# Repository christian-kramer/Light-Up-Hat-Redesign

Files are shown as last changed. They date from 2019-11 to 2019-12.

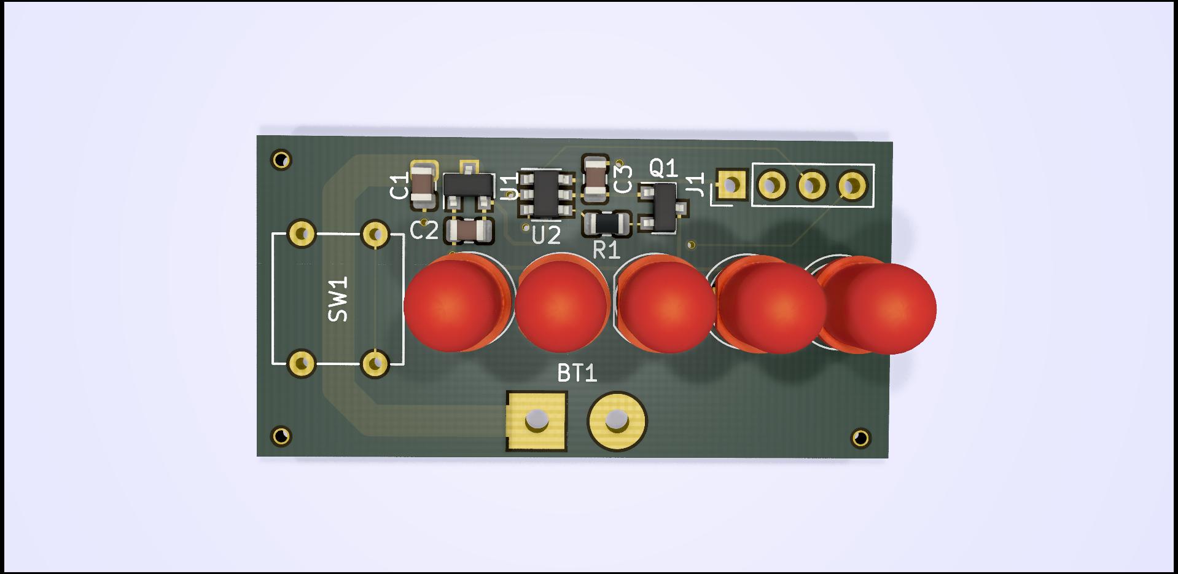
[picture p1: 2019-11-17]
Images/Render.jpg

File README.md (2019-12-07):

# Light-Up-Hat-Redesign
Putting wearable technology in a winter hat

---

Most people, when talking about "hats" in the hobbyist embedded world, are referring to little devices that fit on top of a Raspberry Pi. But no, I'm talking about an actual hat... like the one that goes on your head.

It all starts with a mistake; letting my winter hat with a built-in headlamp go through my wash without taking the electronics out first.

Now, these things aren't terribly expensive to replace. Mine was just $13 on Amazon.

LED Beanie

But being savvy with electronics, I decided I wanted to try to fix mine. But... what I found was rather disheartening.

LED Beanie Circuitry

These things are cheap for a reason, and that reason is they're not very well built. The wires of the battery pack were just barely soldered onto the LED contacts to begin with... any fix I did to this thing was still going to be temporary. Add to that the annoyance of having to turn the switch on the battery pack off with my fingernail, and... I smelled an opportunity for an improvement. To the drawing board!

I knew I wanted to keep the "5-LED array" form factor, but I also wanted a button next to the LEDs I could push to toggle them on and off, so I didn't have to take off my gloves like I currently had to do. I spent a lot of time trying to figure out an all-analog method of doing this push button that didn't require many components. But in the end, I decided I should use up those PIC10F220s I had ordered for my first-ever circuit boards I designed a year ago.

Here's what I came up with for a board:

Hat PCB Render

First off, we've got some nice big through-hole pads for the battery wires to connect to. I want to be able to yank on those things without even budging. Next, we've got the on/off push-button. I decided to use these silicone "soundless tact switches" in place of the typical clicky kind. That way I didn't have to use much force, allowing me to keep my gloves on.

Tact Switch

The battery leads into the nifty XC6206 SOT-23 3.3v regulator I found on eBay from Torex. At $0.40, they're a steal to save some space.

XC6206

The regulator then leads into the ever-faithful PIC10F220, which handles the input of the button and also controls a 2n3906 PNP transistor, also in a SOT-23 package. This drives the 5 LEDs, which should give us plenty of light!

Finally, everything arrived in the mail.

Board Face 1
Board Face 2

The boards turned out great! I opted for black so it would match the hat color, and because I absolutely love JLCPCB's matte black solder mask.

On to assembly!

Assembled

Once everything was put together... it didn't work! No matter what I did, the PIC10F220 just wouldn't talk to my PC! I was starting to have flashbacks to a year ago, when I tried using these PICs for the first time. Maybe I had a bad batch?

I refused to believe that. First thing I did was check to ensure all 6 pins had good contact with the traces... and what do you know! Pin 1, the programming Data Pin, wasn't soldered properly underneath. After some solder paste and a reflow, the PIC talked! So, I whipped up a quick program to turn on the PNP transistor, and... nothing. No light. What gives? I used my multimeter again, which was showing  0v at the base, 3.3v at the emitter, and... 0v at the collector. With a 1KΩ base resistor, there should certainly be enough current flowing to achieve saturation. What in the world? Is my understanding of how transistors work flawed? I pored for hours over schematics and reference designs, trying to figure out why my 2n3906 wasn't turning on. And then, I happened to glance at a diagram for the SOT-23 package pinout.

SOT-23 BJT

I had to do a double-take. Wait, the base is on the *left*?! Oh no, I designed the board with the base on the right!

Bad Design

Problem

The SOT-23 version's base and emitter are swapped from the TO-92 version's. Gah! What do I do now?

Funny enough, this is actually a common design error, even amongst professionals. So common, in fact, that they apparently make reversed versions of SOT-23 BJTs for exactly this occasion, (though probably for cases where re-spinning boards would cost $$$). A hobbyist-level fix is actually to bend the pins and flip the transistor upside-down. Which worked! The LEDs turned on!

Unfortunately, soon after, I accidentally connected the power leads incorrectly, and destroyed the board with 6 volts reverse polarity. But when I tried assembling another board, two of the PIC10F220's pins bridged with solder. Try as I might, I couldn't get them un-bridged... so I tried making *another*. But that one bridged too! At this point, I got so frustrated I gave up on hand-assembling, and decided to try out a new feature of JLCPCB: their SMT Assembly Service.

The way it works is  you go to [this](https://jlcpcb.com/client/index.html#/parts/componentSearch) page and find each component you need in your schematic. When you click on one, it will give you the description, datasheet, and "LCSC Part #". This part number is what you will specify in your schematic symbol's properties, as "LCSC".

Part Search

LCSC

At the end of your design process, when you're ready to export your files for manufacture, there are some extra steps to follow for providing the part coordinates and tooling holes needed, which JLCPCB explains [here](https://support.jlcpcb.com/category/78-smt-assembly).

Finally, the boards arrived, and they looked great! Everything was assembled except for the LEDs, button, and battery pack. And I needed to program them too, of course.

Video of it working on my bench: https://i.imgur.com/HR5HdYS.mp4

Video of it working on my bench, with battery pack: https://i.imgur.com/gJqf0xF.mp4

Video of completed hat (WARNING: Very bright and flashing lights!): https://i.imgur.com/4RvkQvS.mp4

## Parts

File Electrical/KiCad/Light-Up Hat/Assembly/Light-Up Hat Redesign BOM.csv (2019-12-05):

Comment | Designator | Footprint | LCSC Part #
1KΩ | R1 | Resistor_SMD:R_0805_2012Metric | C17513
XC6206 | U1 | Package_TO_SOT_SMD:SOT-23 | C5446
1μF | C1 | Capacitor_SMD:C_0805_2012Metric | C28323
1μF | C2 | Capacitor_SMD:C_0805_2012Metric | C28323
C_Small | C3 | Capacitor_SMD:C_0805_2012Metric | C49678
MMBT3906 | Q1 | Package_TO_SOT_SMD:SOT-23 | C2143
PIC10F200-IOT | U2 | Package_TO_SOT_SMD:SOT-23-6 | C8224

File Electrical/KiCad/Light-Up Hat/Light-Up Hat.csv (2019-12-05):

Source: | L:\Documents\GitHub\Light-Up-Hat-Redesign\Electrical\KiCad\Light-Up Hat\Light-Up Hat.sch
Date: | 11/18/2019 3:20:24 PM
Tool: | Eeschema (5.0.0)
Generator: | L:\Programs\KiCad\bin\scripting\plugins/bom_csv_grouped_by_value.py
Component Count: | 15
Individual Components:
Item | Qty | Reference(s) | Value | LibPart | Footprint | Datasheet | LCSC
 |  | BT1 | Battery_Cell | Device:Battery_Cell | Connector_Wire:SolderWirePad_1x02_P5.08mm_Drill1.5mm | ~
 |  | C1 | 1μF | Device:C_Small | Capacitor_SMD:C_0805_2012Metric | ~ | C28323
 |  | C2 | 1μF | Device:C_Small | Capacitor_SMD:C_0805_2012Metric | ~ | C28323
 |  | C3 | C_Small | Device:C_Small | Capacitor_SMD:C_0805_2012Metric | ~ | C49678
 |  | D1 | LED | Device:LED | LED_THT:LED_D5.0mm | ~
 |  | D2 | LED | Device:LED | LED_THT:LED_D5.0mm | ~
 |  | D3 | LED | Device:LED | LED_THT:LED_D5.0mm | ~
 |  | D4 | LED | Device:LED | LED_THT:LED_D5.0mm | ~
 |  | D5 | LED | Device:LED | LED_THT:LED_D5.0mm | ~
 |  | J1 | Conn_01x04 | Connector_Generic:Conn_01x04 | Connector_PinHeader_2.54mm:PinHeader_1x04_P2.54mm_Vertical | ~
 |  | Q1 | MMBT3906 | Transistor_BJT:MMBT3906 | Package_TO_SOT_SMD:SOT-23 | https://www.fairchildsemi.com/datasheets/2N/2N3906.pdf | C2143
 |  | R1 | 1KΩ | Device:R_Small | Resistor_SMD:R_0805_2012Metric | ~ | C17513
 |  | SW1 | SW_SPST | Switch:SW_SPST | Button_Switch_THT:SW_PUSH_8mm_H5mm
 |  | U1 | XC6206 | Regulator_Linear:AP1117-33 | Package_TO_SOT_SMD:SOT-23 | http://www.diodes.com/datasheets/AP1117.pdf | C5446
 |  | U2 | PIC10F200-IOT | MCU_Microchip_PIC10:PIC10F200-IOT | Package_TO_SOT_SMD:SOT-23-6 | http://ww1.microchip.com/downloads/en/DeviceDoc/41239D.pdf | C8224
Collated Components:
Item | Qty | Reference(s) | Value | LibPart | Footprint | Datasheet | LCSC
1 | 1 | BT1 | Battery_Cell | Device:Battery_Cell | Connector_Wire:SolderWirePad_1x02_P5.08mm_Drill1.5mm | ~
2 | 2 | C1, C2 | 1μF | Device:C_Small | Capacitor_SMD:C_0805_2012Metric | ~ | C28323
3 | 1 | C3 | C_Small | Device:C_Small | Capacitor_SMD:C_0805_2012Metric | ~ | C49678
4 | 5 | D1, D2, D3, D4, D5 | LED | Device:LED | LED_THT:LED_D5.0mm | ~
5 | 1 | J1 | Conn_01x04 | Connector_Generic:Conn_01x04 | Connector_PinHeader_2.54mm:PinHeader_1x04_P2.54mm_Vertical | ~
6 | 1 | Q1 | MMBT3906 | Transistor_BJT:MMBT3906 | Package_TO_SOT_SMD:SOT-23 | https://www.fairchildsemi.com/datasheets/2N/2N3906.pdf | C2143
7 | 1 | R1 | 1KΩ | Device:R_Small | Resistor_SMD:R_0805_2012Metric | ~ | C17513
8 | 1 | SW1 | SW_SPST | Switch:SW_SPST | Button_Switch_THT:SW_PUSH_8mm_H5mm
9 | 1 | U1 | XC6206 | Regulator_Linear:AP1117-33 | Package_TO_SOT_SMD:SOT-23 | http://www.diodes.com/datasheets/AP1117.pdf | C5446
10 | 1 | U2 | PIC10F200-IOT | MCU_Microchip_PIC10:PIC10F200-IOT | Package_TO_SOT_SMD:SOT-23-6 | http://ww1.microchip.com/downloads/en/DeviceDoc/41239D.pdf | C8224

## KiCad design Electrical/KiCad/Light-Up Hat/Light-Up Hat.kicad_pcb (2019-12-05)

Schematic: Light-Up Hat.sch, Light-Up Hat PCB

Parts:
BT1: Battery_Cell; SolderWirePad_1x02_P5.08mm_Drill1.5mm
C1, C2: 1μF; C_0805_2012Metric; LCSC C28323
C3: C_Small; C_0805_2012Metric; LCSC C49678
D1, D2, D3, D4, D5: LED; LED_D5.0mm
J1: Conn_01x04; PinHeader_1x04_P2.54mm_Vertical
Q1: MMBT3906; SOT-23; LCSC C2143
R1: 1KΩ; R_0805_2012Metric; LCSC C17513
SW1: SW_SPST; SW_PUSH_8mm_H5mm
U1: XC6206; SOT-23; LCSC C5446
U2: PIC10F200-IOT; SOT-23-6; LCSC C8224

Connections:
+3V3: C2.1, C3.1, Q1.2 (E), U1.2 (VO), U2.5
+BATT: BT1.1, C1.1, U1.3 (VI)
/BUTTON_INPUT: J1.4, SW1.1, U2.3
/ICSPDAT: J1.3, U2.1
/LED_CONTROL: R1.2, U2.4
GND: BT1.2, C1.2, C2.2, C3.2, D1.1, D2.1, D3.1, D4.1, D5.1, J1.2, SW1.2, U1.1 (GND), U2.2
unnamed: D1.2, D2.2, D3.2, D4.2, D5.2, Q1.3 (C)
unnamed: Q1.1 (B), R1.1
VPP: J1.1, U2.6

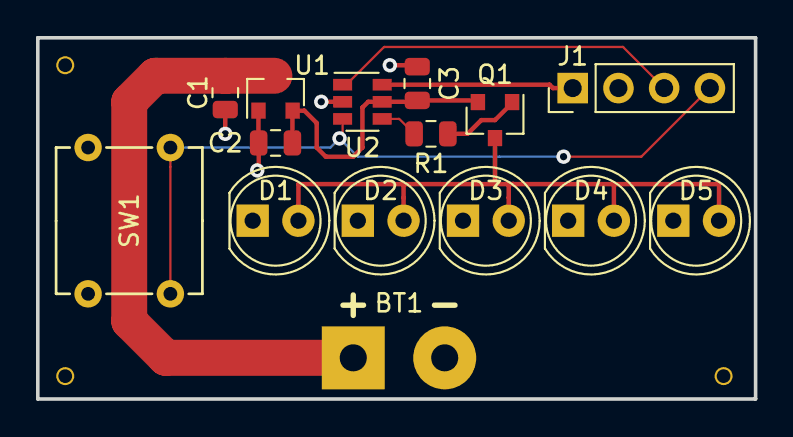
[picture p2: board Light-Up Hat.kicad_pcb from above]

Board: 2 copper layers, 39.9 x 20.1 mm, 15 parts (0 on the bottom side), 9 nets.

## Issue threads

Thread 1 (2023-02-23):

Light-Up-Hat-Redesign

diks2003, 2023-02-23:
Good afternoon. Why is the project for a hat with a lantern not working? The LED flashing project works, which is located in a neighboring folder, and the cap flashlight does not work, although everything is done by analogy.

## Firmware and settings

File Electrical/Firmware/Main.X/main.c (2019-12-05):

/* 
 * File:   main.c
 * Author: Christian Kramer
 *
 * Created on November 15, 2019, 8:45 PM
 */
#define _XTAL_FREQ 8000000
// CONFIG
#pragma config IOSCFS = 8MHZ    // Internal Oscillator Frequency Select bit (8 MHz)
#pragma config MCPU = ON        // Master Clear Pull-up Enable bit (Pull-up enabled)
#pragma config WDTE = OFF       // Watchdog Timer Enable bit (WDT disabled)
#pragma config CP = OFF         // Code protection bit (Code protection off)
#pragma config MCLRE = ON       // GP3/MCLR Pin Function Select bit (GP3/MCLR pin function is MCLR)

// #pragma config statements should precede project file includes.
// Use project enums instead of #define for ON and OFF.

#include <xc.h>

#include <stdio.h>
#include <stdlib.h>

/*
 * 
 */
int main(int argc, char** argv) {

    OPTION = 0b00000000;
    OSCCALbits.FOSC4 = 0; //disable oscillator output on GP2
    TRISGPIO = 0b00000010;
    
    while (1) {
        
        //if ((GPIO >> 1) & 1U) {
            //GPIO ^= 1UL << 2;
        //}
        
        GPIO = 0b00000100;
        __delay_ms(1000);
        GPIO = 0b00000000;
        __delay_ms(1000);
        
    }
    return (EXIT_SUCCESS);
}

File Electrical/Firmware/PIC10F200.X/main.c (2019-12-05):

/* 
 * File:   main.c
 * Author: flyhi
 *
 * Created on December 5, 2019, 11:11 AM
 */
#define _XTAL_FREQ 4000000

// CONFIG
#pragma config WDTE = OFF       // Watchdog Timer (WDT disabled)
#pragma config CP = OFF         // Code Protect (Code protection off)
#pragma config MCLRE = ON       // Master Clear Enable (GP3/MCLR pin function  is MCLR)

// #pragma config statements should precede project file includes.
// Use project enums instead of #define for ON and OFF.

#include <xc.h>

#include <stdio.h>
#include <stdlib.h>
#include <stdint.h>

/*
 * 
 */
int main(int argc, char** argv) {
    OSCCALbits.FOSC4 = 0; //disable oscillator output on GP2
    OPTION = 0b10000000;
    TRISGPIO = 0b00000010;
    
    uint8_t ledstate = 0;
    
    uint8_t flashcounter = 0;
    
    
    while(1) {
        
        if (!((GPIO >> 1) & 1U)) {
            //button pressed
            __delay_ms(50);
            if (!((GPIO >> 1) & 1U)) {
                //button has passed de-bounce, this is a press
                uint16_t lengthcount = 0;
                
                while((!((GPIO >> 1) & 1U)) && lengthcount < 2000){
                    //button is being held
                    lengthcount++;
                    __delay_ms(1);
                };
                
                if (lengthcount < 500) {
                    //short press
                    
                    //were we just in emergency mode?
                    if ((ledstate >> 3) & 1U) {
                        //clear emergency and led
                        ledstate &= ~(1UL << 3);
                        ledstate &= ~(1UL << 2);                        
                    } else {
                        //toggle state bit
                        ledstate ^= 1UL << 2;

                        //clear emergency bit
                        ledstate &= ~(1UL << 3);
                    }
                } else {
                    //long press
                    
                    //set emergency bit
                    ledstate |= 1UL << 3;
                }
            }
        }
        
        if ((ledstate >> 3) & 1U) {
            //emergency mode
            if (++flashcounter > 100) {
                flashcounter = 0;
                GPIO ^= 1UL << 2;
            }
            __delay_ms(1);
        } else {
            //not emergency mode
            GPIO ^= (-(!((ledstate >> 2) & 1U)) ^ GPIO) & (1UL << 2);
        }
    }
    
    return (EXIT_SUCCESS);
}

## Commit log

2019-10-20 rough draft of design without values
    [Light-Up Hat.kicad_pcb, Light-Up Hat.sch]
2019-10-31 PCB For Manufacture
    [Light-Up Hat-B.Cu.gbr, Light-Up Hat-B.Mask.gbr, Light-Up Hat-B.Paste.gbr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]
2019-11-17 Hat LEDs blink on and off every 1 second
    [Light-Up Hat.kicad_pcb, Light-Up Hat.sch]
2019-12-05 fixed board design for new revision
    [Light-Up Hat Redesign BOM.csv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]
2019-12-05 working firmware for on, off, emergency mode
    [Light-Up Hat-PTH.drl]
